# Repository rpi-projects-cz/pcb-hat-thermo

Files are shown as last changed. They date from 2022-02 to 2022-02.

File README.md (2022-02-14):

# Project pcb-hat-thermo

Goal of this project is to design Raspberry Pi Zero extension HAT to support DS18B20 senzor based thermometers that are using 1-wire protocol via GPIO 04.

Intended HAT needs to be stackable and compatible with other modules unless they are using GPIO 04 PIN.

The cirquit is using Pull-Up resistor R1 to deliver 3.3v voltage, generating logical 1 value on DATA pin. In order to generate logical 0 value, the temperature sensor will short the DATA pin to ground and deliver 0v voltage on DATA pin. Because direct wiring between DATA pin and 3.3v might damage Raspberry Pi, we are using resistore R1 10kΩ to reduce electrical current to acceptable value of 0.33 mA (maximum is 0.5 mA).

```text
Current (A) = Voltage (V) / Resistency (R) = 3.3V / 10000Ω = 0.00033 A = 0.33 mA
```

Reference architecture for this design is based on following article and associated cabling diagram.

- [Raspberry Pi DS18B20 Temperature Sensor Tutorial](https://www.circuitbasics.com/raspberry-pi-ds18b20-temperature-sensor-tutorial/)

Wiring for SSH Terminal Output

This PCB is designed in [KiCad](https://www.kicad.org) 6.0.1-0.

## Logical Design

Following picture is capturing logical design.

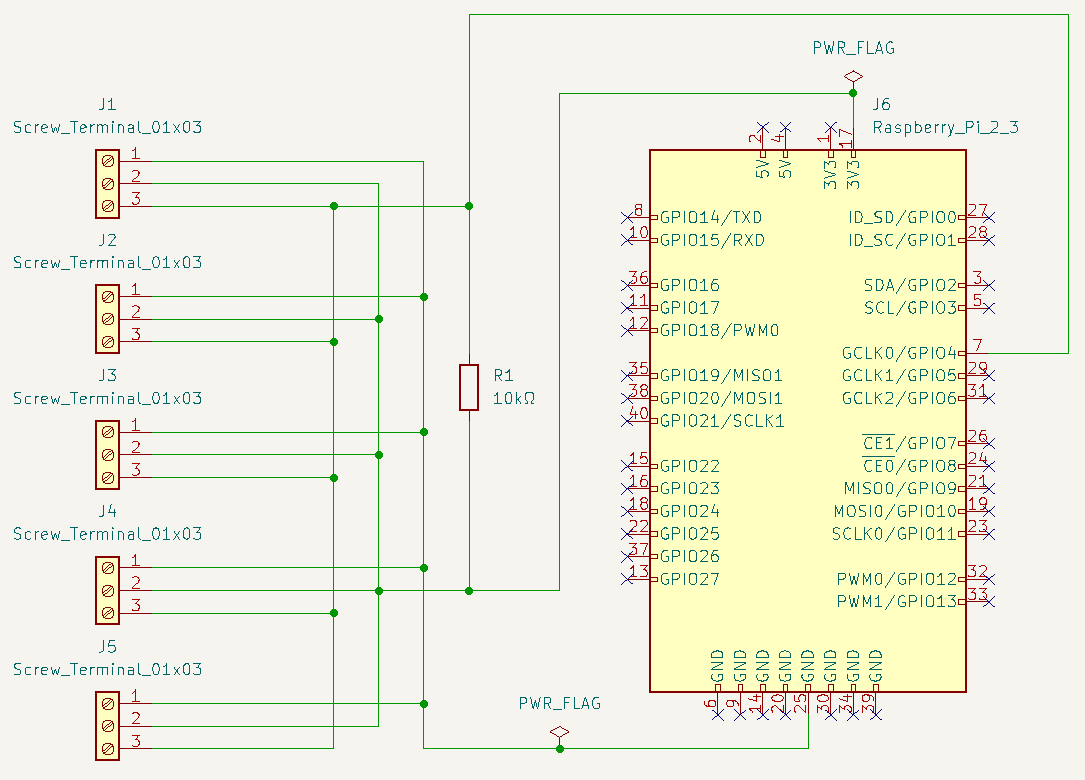
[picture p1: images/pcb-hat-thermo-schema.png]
Logical Design


There are five Phoenix Horizontal 1x03 P3.50mm connectors on the board, each with following connectivity:

- GND - Ground, connected to PIN 25
- 3.3v - VCC power 3.3v, connected to PIN 17
- DAT - Data, 1-wire protocol data connected to PIN 07 (GPIO 04)

Since the 1-wire protocol is addressable, all connectors are wired in chain, having Pull-Up resistor R1 10kΩ between DAT and 3.3v links.

Resistor R1 is 10kΩ SMD resistor with form factor [0805](https://en.wikipedia.org/wiki/List_of_integrated_circuit_packaging_types#Rectangular_passive_components).

## Physical Design

Pictures below are visualizing the final PCB as designed in KiCad.

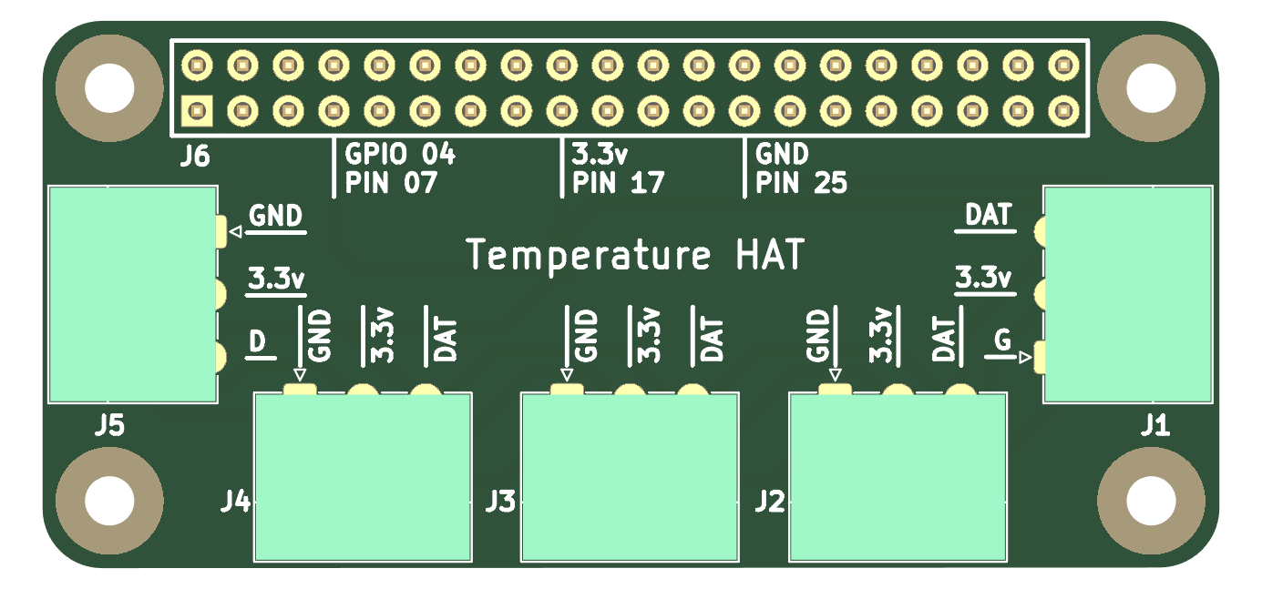
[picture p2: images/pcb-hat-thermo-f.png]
Flat front

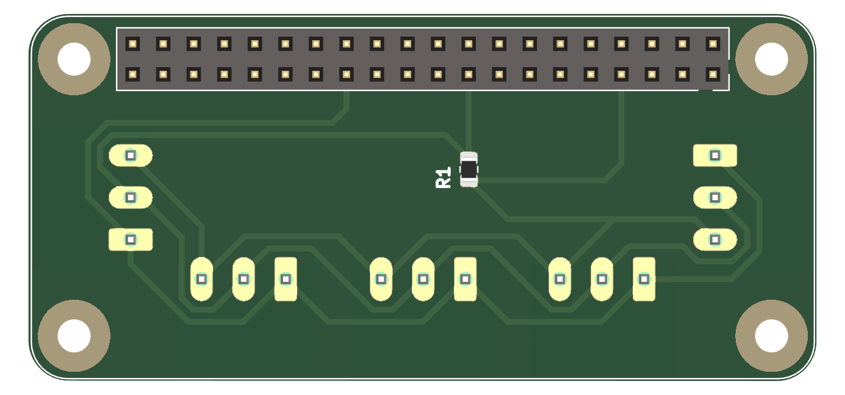
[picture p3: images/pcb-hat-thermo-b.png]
Flat back

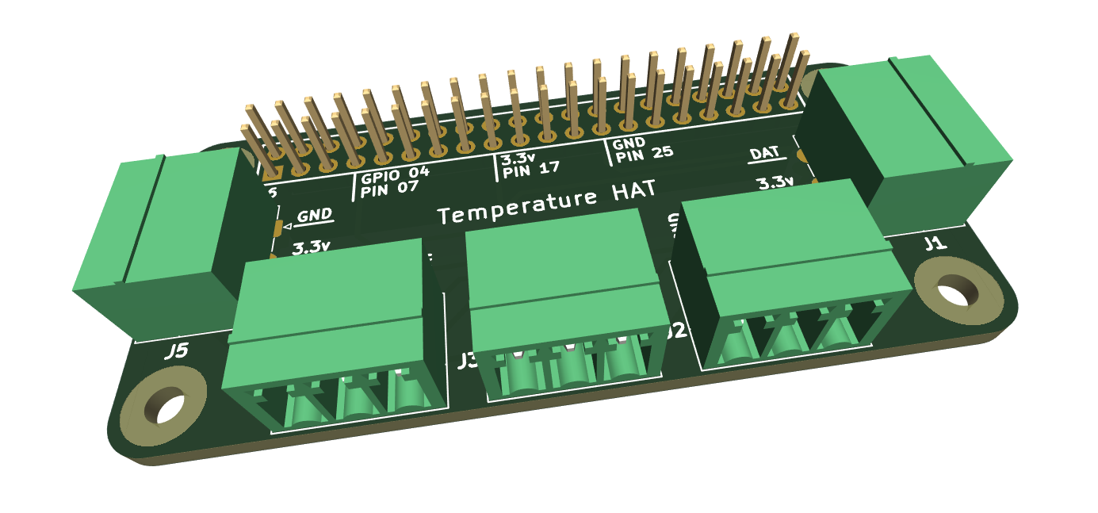
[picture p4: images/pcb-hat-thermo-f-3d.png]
3D front

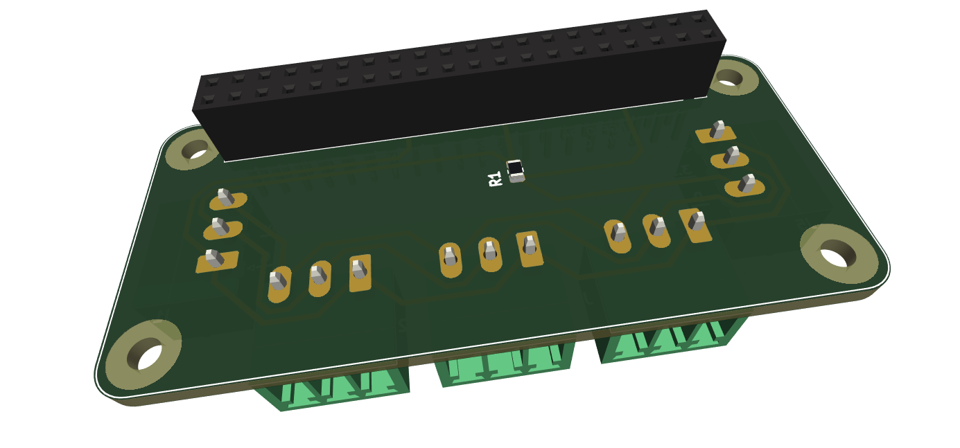
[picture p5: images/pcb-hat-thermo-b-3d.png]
3D back


Source files, including `kicad_pcb` are in the [KiCad/pcb-hat-thermo](KiCad/pcb-hat-thermo) directory.

## Contributing

This is open source project based on Eclipse public license. Any feedback, suggestions, correction or any other contributions are highly welcomed.

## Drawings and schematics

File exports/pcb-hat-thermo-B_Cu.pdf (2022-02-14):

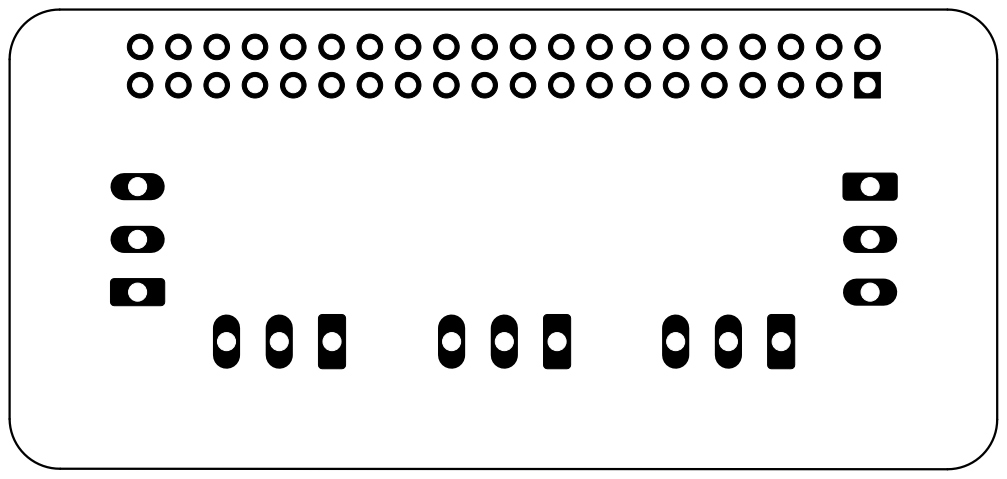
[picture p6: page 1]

File: pcb-hat-thermo.kicad_pcb Sheet: Tomas Krojzl

Id: 1/1 Title: Raspbery Pi Zero - Thermometer HAT PCB

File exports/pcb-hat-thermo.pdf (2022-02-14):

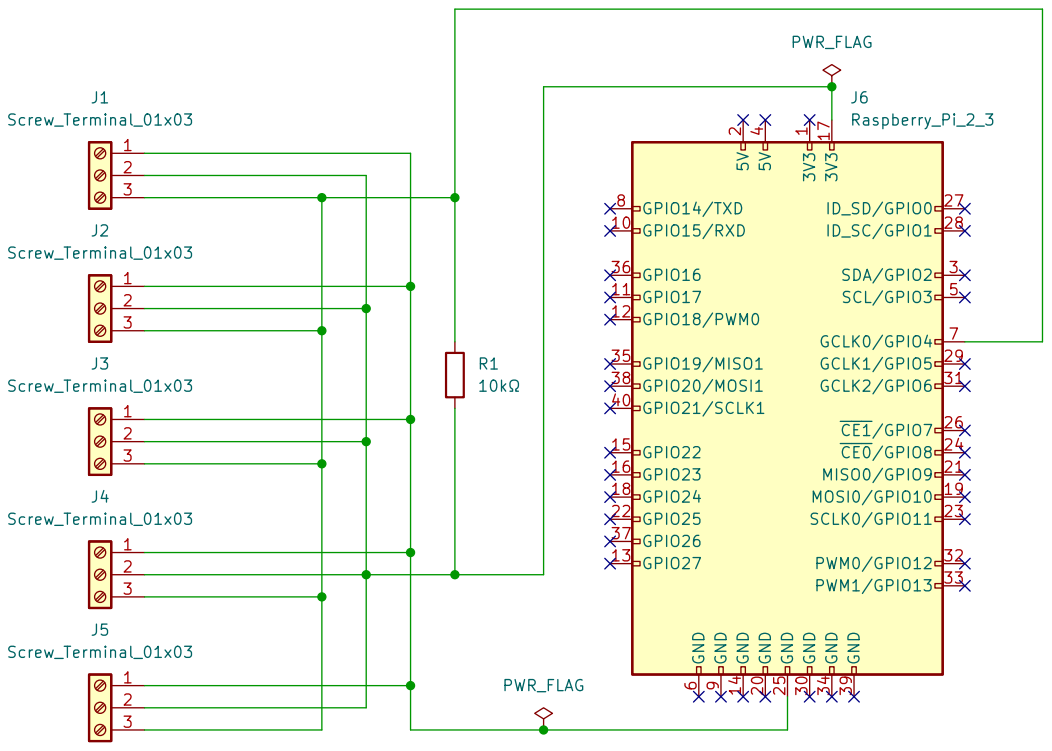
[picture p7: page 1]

File: pcb-hat-thermo.kicad_sch Sheet: / Tomas Krojzl

Id: 1/1 Title: Raspbery Pi Zero - Thermometer HAT PCB

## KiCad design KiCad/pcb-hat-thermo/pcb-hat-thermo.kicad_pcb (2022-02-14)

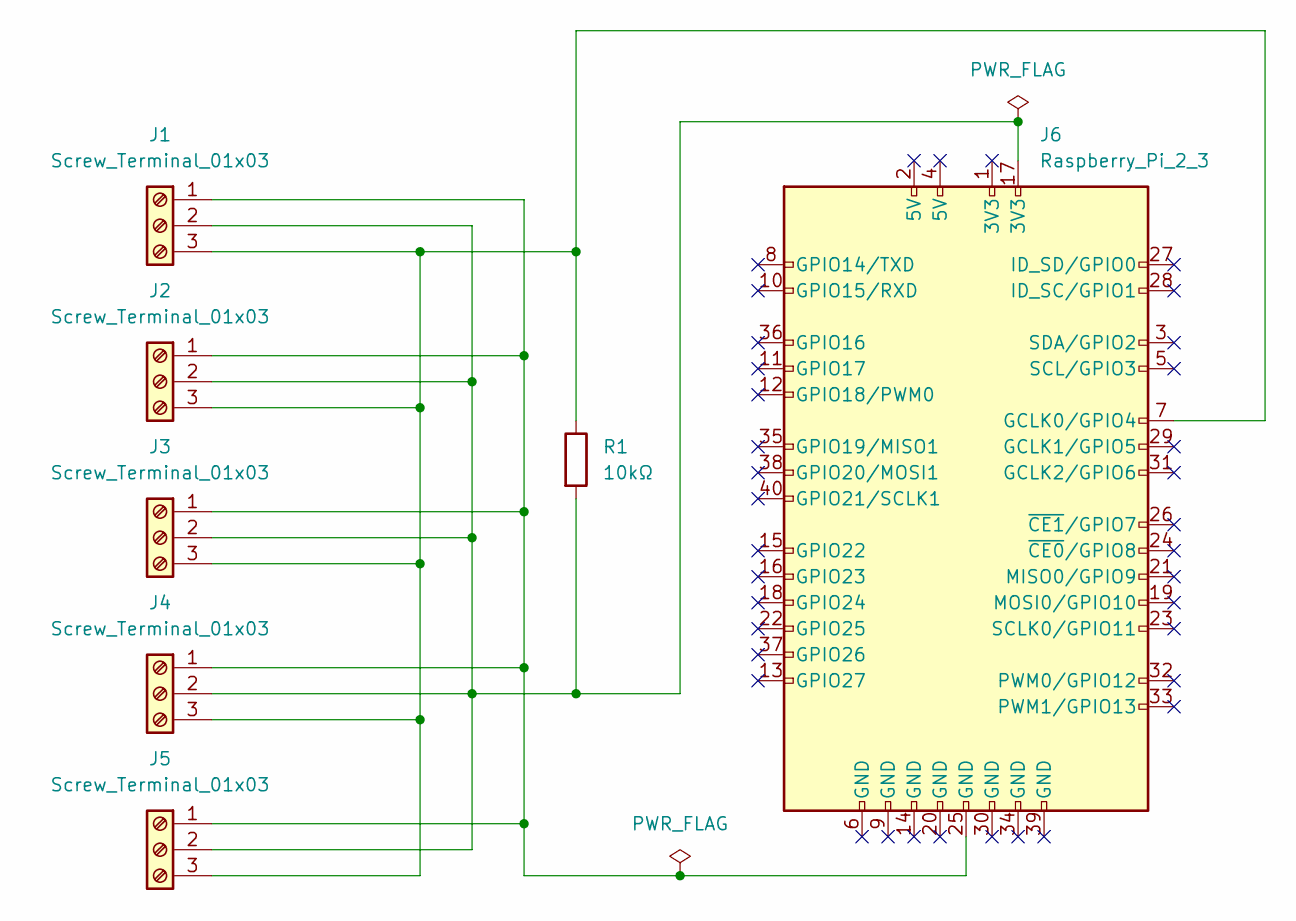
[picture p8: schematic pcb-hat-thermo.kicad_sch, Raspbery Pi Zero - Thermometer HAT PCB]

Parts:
J1, J2, J3, J4, J5: Screw_Terminal_01x03; PhoenixContact_MC_1,5_3-G-3.5_1x03_P3.50mm_Horizontal
J6: Raspberry_Pi_2_3; Raspberry_Pi_Zero_Custom_with_Header
R1: 10kΩ; R_0805_2012Metric

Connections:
unnamed: J1.1, J2.1, J3.1, J4.1, J5.1, J6.25 (GND)
unnamed: J1.2, J2.2, J3.2, J4.2, J5.2, J6.17 (3V3), R1.2
unnamed: J1.3, J2.3, J3.3, J4.3, J5.3, J6.7 (GCLK0/GPIO4), R1.1

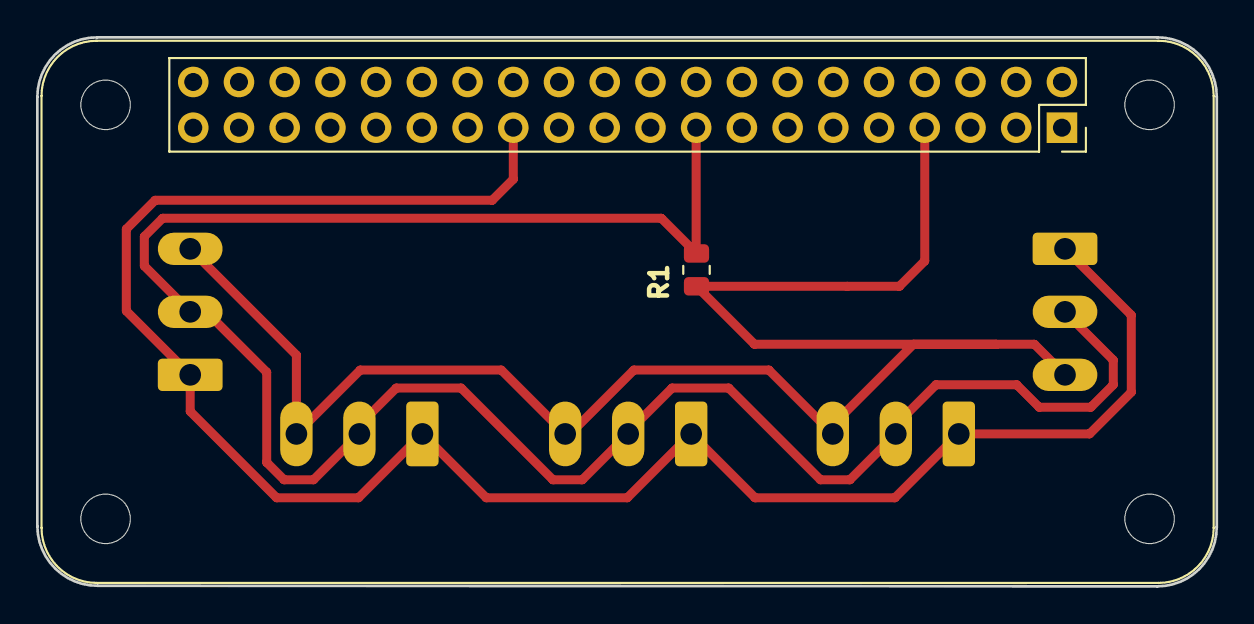
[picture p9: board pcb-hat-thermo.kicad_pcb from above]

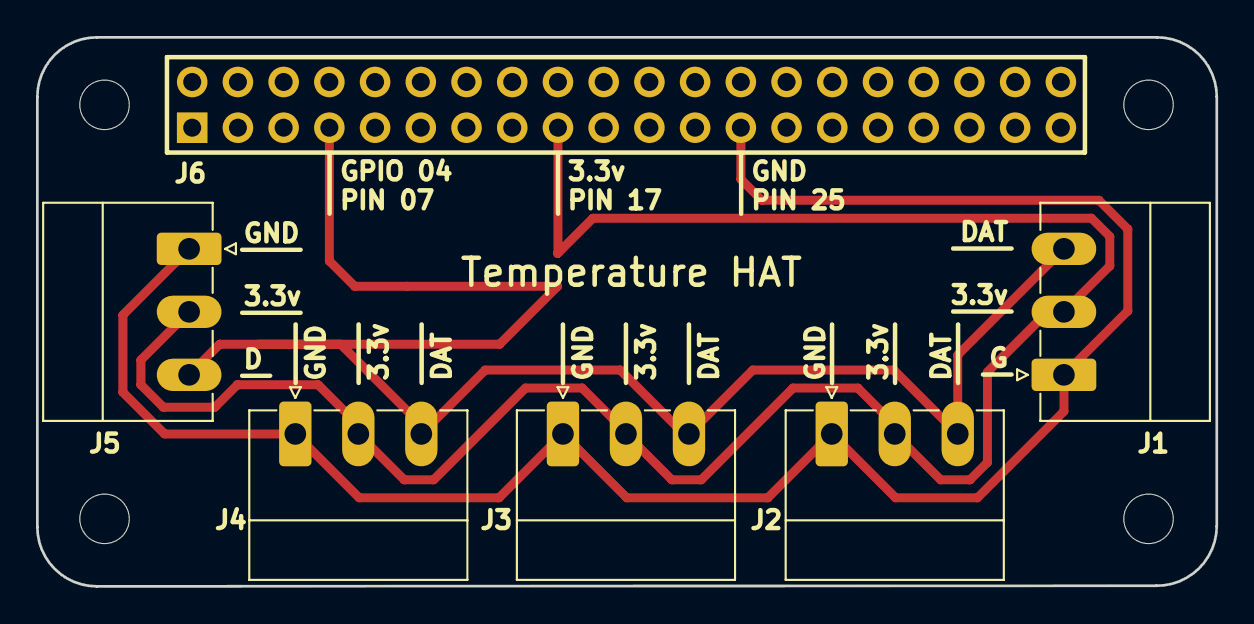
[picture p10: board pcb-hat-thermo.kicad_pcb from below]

Board: 2 copper layers, 65.5 x 30.5 mm, 7 parts (5 on the bottom side), 3 nets.

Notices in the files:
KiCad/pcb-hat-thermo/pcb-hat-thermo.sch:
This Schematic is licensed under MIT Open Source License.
